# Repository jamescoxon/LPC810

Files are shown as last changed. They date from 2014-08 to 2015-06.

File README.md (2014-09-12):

Adapted from LPC810_CodeBase

* Updated SPI driver
* New driver for RFM69 Radio module
* UART code using interrupt and buffer
* GPS code to read Ublox GPS modules
* Stripped down version of string library
* Included memcpy

Please remember to edit src/main.c and add your own node ID and location string.

LPC810_CodeBase
===============

Open source code base for the ARM Cortex M0+ LPC810 family from NXP.

This code base is intended to work with the LPC810 in a DIP8 package.  While these drivers are based on the original LPC800 example code from NXP, the LPC810 has limited resources (4KB flash and 1KB SRAM), so smaller, lighter-weight drivers had to be written to get the most out of these resources we have.

The current code implements the following peripheral drivers:

- A basic SPI driver
- Some simple GPIO helper functions (although GPIO should normally be accessed directly via the appropriate registers)
- A simple driver for UART0 and printf-redirection that allows 'printf' output to be transmitted to UART0
- A basic multi-rate timer driver that allows us to set delays

The code base also implements a mini printf that takes up much less space than the default printf used in most libc variants.  If necessary, it's easy to change the printf redirection to a location other than UART0 via the printf-redirection.c file.

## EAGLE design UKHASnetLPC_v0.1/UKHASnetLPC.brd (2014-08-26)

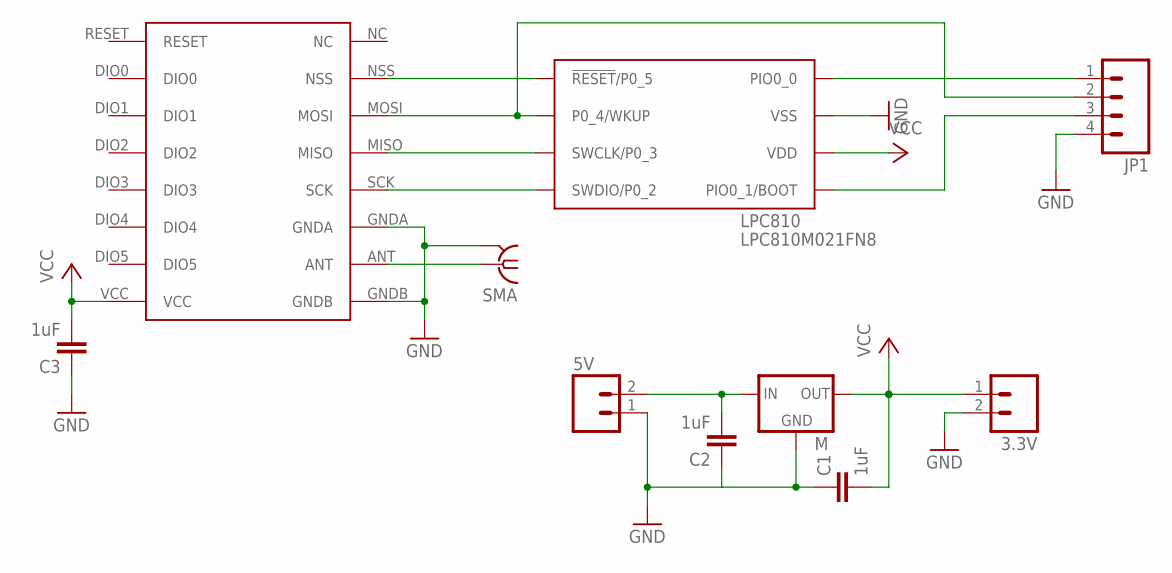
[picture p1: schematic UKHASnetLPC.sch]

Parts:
3.3V, 5V: M02LOCK; 1X02_LOCK
C1, C2, C3: 1uF; CAP-PTH-SMALL
JP1: M04PTH; 1X04
LPC810: LPC810M021FN8; DIP8
M: MCP1700INLINE; TO92-INLINE
RFM69: RFM69HW; RFM
SMA: BUS-SMA

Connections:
GND: 3.3V.2, 5V.1, C1.1, C2.1, C3.1, JP1.4, LPC810.P$7 (VSS), M.1 (GND), RFM69.GNDA, RFM69.GNDB, SMA.2 (GND), SMA.3 (GND), SMA.4 (GND), SMA.5 (GND)
unnamed: LPC810.P$1 (!RESET!/P0_5), RFM69.NSS
unnamed: JP1.2, LPC810.P$2 (P0_4/WKUP), RFM69.MOSI
unnamed: LPC810.P$3 (SWCLK/P0_3), RFM69.MISO
unnamed: LPC810.P$4 (SWDIO/P0_2), RFM69.SCK
unnamed: JP1.3, LPC810.P$5 (PIO0_1/BOOT)
unnamed: JP1.1, LPC810.P$8 (PIO0_0)
unnamed: RFM69.ANT, SMA.1
unnamed: 5V.2, C2.2, M.2 (IN)
VCC: 3.3V.1, C1.2, C3.2, LPC810.P$6 (VDD), M.3 (OUT), RFM69.VCC

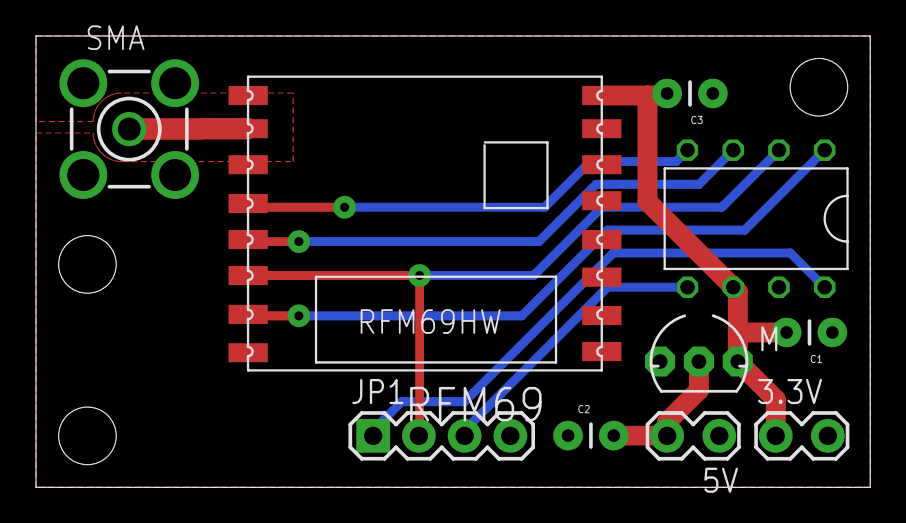
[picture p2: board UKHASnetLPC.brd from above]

Board: 4 copper layers, 46.3 x 25.1 mm, 10 parts (0 on the bottom side), 10 nets.

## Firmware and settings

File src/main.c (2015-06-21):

/**************************************************************************/
/*!
 @file     main.c
 
 @section LICENSE
 
 Software License Agreement (BSD License)
 
 Copyright (c) 2013, K. Townsend (microBuilder.eu)
 All rights reserved.
 
 Modified James Coxon (jacoxon@googlemail.com) 2014-2015
 
 Redistribution and use in source and binary forms, with or without
 modification, are permitted provided that the following conditions are met:
 1. Redistributions of source code must retain the above copyright
 notice, this list of conditions and the following disclaimer.
 2. Redistributions in binary form must reproduce the above copyright
 notice, this list of conditions and the following disclaimer in the
 documentation and/or other materials provided with the distribution.
 3. Neither the name of the copyright holders nor the
 names of its contributors may be used to endorse or promote products
 derived from this software without specific prior written permission.
 
 THIS SOFTWARE IS PROVIDED BY THE COPYRIGHT HOLDERS ''AS IS'' AND ANY
 EXPRESS OR IMPLIED WARRANTIES, INCLUDING, BUT NOT LIMITED TO, THE IMPLIED
 WARRANTIES OF MERCHANTABILITY AND FITNESS FOR A PARTICULAR PURPOSE ARE
 DISCLAIMED. IN NO EVENT SHALL THE COPYRIGHT HOLDER BE LIABLE FOR ANY
 DIRECT, INDIRECT, INCIDENTAL, SPECIAL, EXEMPLARY, OR CONSEQUENTIAL DAMAGES
 (INCLUDING, BUT NOT LIMITED TO, PROCUREMENT OF SUBSTITUTE GOODS OR SERVICES;
 LOSS OF USE, DATA, OR PROFITS; OR BUSINESS INTERRUPTION) HOWEVER CAUSED AND
 ON ANY THEORY OF LIABILITY, WHETHER IN CONTRACT, STRICT LIABILITY, OR TORT
 (INCLUDING NEGLIGENCE OR OTHERWISE) ARISING IN ANY WAY OUT OF THE USE OF THIS
 SOFTWARE, EVEN IF ADVISED OF THE POSSIBILITY OF SUCH DAMAGE.
 */
/**************************************************************************/
//Node settings have been moved seperate file "settings.h"
#include "settings.h"

#include <stdio.h>
#include "LPC8xx.h"
#include "mrt.h"
#include "spi.h"
#include "rfm69.h"

#ifdef defined(GATEWAY) || defined(DEBUG) || defined(GPS)
    #include "uart.h"
#endif

#ifdef GPS
    #include "gps.h"
#endif

#ifdef ADC
    #include "adc.h"
#endif

#ifdef ZOMBIE
    #include "zombie.h"
#endif

#ifdef SERIAL_IN
    #include "uart.h"
    char data_out_temp[MAX_TX_CHARS+1];
#endif

char data_temp[66];

uint8_t data_count = 96; // 'a' - 1 (as the first function will at 1 to make it 'a'
unsigned int rx_packets = 0, random_output = 0, rx_restarts = 0;
int16_t rx_rssi, floor_rssi, rssi_threshold, adc_result = 0;
/**
 * Setup all pins in the switch matrix of the LPC810
 */
void configurePins() {
    /* Enable SWM clock */
    LPC_SYSCON->SYSAHBCLKCTRL |= (1<<7);
    
    /* Pin Assign 8 bit Configuration */
    /* U0_TXD */
    LPC_SWM->PINASSIGN0 = 0xffffff00UL;
    /* SPI0_SCK */
    LPC_SWM->PINASSIGN3 = 0x02ffffffUL;
    /* SPI0_MOSI */
    /* SPI0_MISO */
    /* SPI0_SSEL */
    LPC_SWM->PINASSIGN4 = 0xff050304UL;
    
    /* Pin Assign 1 bit Configuration */
    /* ACMP_I2 */
    LPC_SWM->PINENABLE0 = 0xfffffffdUL;
    
}

#ifdef SERIAL_IN
/**
 * Checks for incoming serial data which will be send by radio. This function
 * also checks the buffers length to avoid a stackoverflow at the radio FIFO.
 */
inline void checkTxBuffer(void) {
	uint8_t i;

	if(UART0_available() > 0) {
		for(i=0; i<serialBuffer_write; i++) {

			if(serialBuffer[i] == '\r' ||  serialBuffer[i] == '\n' || strlen(data_out_temp) >= 32) { // Transmit data from buffer

				#ifdef DEBUG
				if(strlen(data_out_temp) >= MAX_TX_CHARS)
					printf("max. buffer exceeded\r\n");
				#endif

				// Transmit data
				incrementPacketCount();

				uint8_t n;
				data_temp[0] = '\0';

				n = sprintf(data_temp, "%d%c%s[%s]", NUM_REPEATS, data_count, data_out_temp, NODE_ID);
				transmitData(n);

				data_out_temp[0] = '\0'; // Flush buffer

			} else {
				sprintf(data_out_temp, "%s%c", data_out_temp, serialBuffer[i]); // Read from serial buffer
			}

		}
		serialBuffer_write = 0;
	}
}
#endif

/**
 * Packet data transmission
 * @param Packet length
 */
void transmitData(uint8_t i) {

    #ifdef GATEWAY
        printf("rx: %s|0\r\n", data_temp);
    #endif

#ifdef ZOMBIE_MODE
    if (data_count == 97) {
       RFM69_send(data_temp, i, 10);
    }
    else {
        // Transmit the data (need to include the length of the packet and power in dbmW)
        RFM69_send(data_temp, i, POWER_OUTPUT);
    }

    RFM69_setMode(RFM69_MODE_SLEEP);
#else
    
    // Transmit the data (need to include the length of the packet and power in dbmW)
    RFM69_send(data_temp, i, POWER_OUTPUT);
    
    //Ensure we are in RX mode
    RFM69_setMode(RFM69_MODE_RX);
#endif

}

/**
 * This function is called when a packet is received by the radio. It will
 * process the packet.
 */
inline void processData(uint32_t len) {
    uint8_t i, packet_len;
    
    for(i=0; i<len; i++) {
        //finds the end of the packet
        if(data_temp[i] != ']')
            continue;
        
        //then terminates the string, ignore everything afterwards
        data_temp[i+1] = '\0';
        
        //Check validity of string
        // 1) is the first position in array a number
        //printf("%d\r\n", data_temp[0]);
        if((int)data_temp[0] <= 48 || (int)data_temp[0] > 57) {
            //printf("Error1\r\n");
            break;
        }
        
        // 2) is the second position in array a letter
        //      < 'a' or > 'z' then break
        //printf("%d\r\n", data_temp[1]);
        if((int)data_temp[1] < 97 || (int)data_temp[1] > 122){
            //printf("Error2\r\n");
            break;
        }
        
#ifdef GATEWAY
        printf("rx: %s|%d\r\n",data_temp, RFM69_lastRssi());
#endif
        //Reduce the repeat value
        data_temp[0] = data_temp[0] - 1;
        //Now add , and end line and let string functions do the rest
        data_temp[i] = ',';
        data_temp[i+1] = '\0';
        
        if(strstr(data_temp, NODE_ID) != 0)
            break;
        
        strcat(data_temp, NODE_ID); // Add ID
        strcat(data_temp, "]"); // Add ending
        
        packet_len = strlen(data_temp);
        mrtDelay(random_output); // Random delay to try and avoid packet collision
        
        rx_packets++;
        
        transmitData(packet_len);
        break;
    }
}

/**
 * It processing incoming data by the radio or serial connection. This function
 * has to be continously called to keep the node running. This function also
 * adds a delay which is specified as 100ms per unit. Therefore 1000 = 100 sec
 * @param countdown delay added to this function
 */
void awaitData(int countdown) {

    uint8_t rx_len, flags1, old_flags1 = 0x90;

    //Clear buffer
    data_temp[0] = '\0';

    RFM69_setMode(RFM69_MODE_RX);

    rx_restarts = 0;

    while(countdown > 0) {

        flags1 = spiRead(RFM69_REG_27_IRQ_FLAGS1);
#ifdef DEBUG
        if (flags1 != old_flags1) {
            printf("f1: %02x\r\n", flags1);
            old_flags1 = flags1;
        }
#endif
        if (flags1 & RF_IRQFLAGS1_TIMEOUT) {
            // restart the Rx process
            spiWrite(RFM69_REG_3D_PACKET_CONFIG2, spiRead(RFM69_REG_3D_PACKET_CONFIG2) | RF_PACKET2_RXRESTART);
            rx_restarts++;
            // reset the RSSI threshold
            floor_rssi = RFM69_sampleRssi();
#ifdef DEBUG
            // and print threshold
            printf("Restart Rx %d\r\n", RFM69_lastRssiThreshold());
#endif
        }
        // Check rx buffer
        if(RFM69_checkRx() == 1) {
            RFM69_recv(data_temp,  &rx_len);
            data_temp[rx_len - 1] = '\0';
            processData(rx_len);
        }

        #ifdef SERIAL_IN
                // Check tx buffer
                checkTxBuffer();
        #endif

        countdown--;
        mrtDelay(100);
    }
}

/**
 * Increments packet count which is transmitted in the beginning of each
 * packet. This function has to be called every packet which is initially
 * transmitted by this node.
 * Packet count is starting with 'a' and continues up to 'z', thereafter
 * it's continuing with 'b'. 'a' is only transmitted at the very first
 * transmission!
 */
void incrementPacketCount(void) {
    data_count++;
    // 98 = 'b' up to 122 = 'z'
    if(data_count > 122) {
        data_count = 98; //'b'
    }
}



int main(void)
{
#ifdef BrownOut
    LPC_SYSCON->BODCTRL = 0x11;  //Should be set to Level 1 (Assertion 2.3V, De-assertion 2.4V) reset
#endif
    
#ifdef GPS
    // Initialise the UART0 block for printf output
    uart0Init(9600);
#elif defined(GATEWAY) || defined(DEBUG)
    // Initialise the UART0 block for printf output
    uart0Init(115200);
#endif
    
    // Configure the multi-rate timer for 1ms ticks
    mrtInit(__SYSTEM_CLOCK/1000);

    /* Enable AHB clock to the Switch Matrix , UART0 , GPIO , IOCON, MRT , ACMP */
    LPC_SYSCON->SYSAHBCLKCTRL |= (1 << 7) | (1 << 14) /*| (1 << 6)*//* | (1 << 18)*/
    | (1 << 10) | (1 << 19);
    
    // Configure the switch matrix (setup pins for UART0 and SPI)
    configurePins();

    
#ifdef DEBUG
    printf("Node Booted\r\n");
#endif
    
#ifdef ADC
    /* Initialise the comparator ICMP_2 */
    LPC_SYSCON->PDRUNCFG &= ~((1 << 15)); // power up ACMP
#endif
    
    //Seed random number generator, we can use our 'unique' ID
    random_output = NODE_ID[0] + NODE_ID[1] + NODE_ID[2];
    
    RFM69_init();
    
#ifdef ZOMBIE_MODE
    RFM69_setMode(RFM69_MODE_SLEEP);
    init_sleep();
    sleepMicro(60000);
#endif
    
#ifdef GPS
		int navmode = 9;
		setupGPS();
#endif
    
#ifdef DEBUG
		printf("Node initialized, version %s\r\n",GIT_VER);
#endif
    
    while(1) {
        
#ifdef GPS
			mrtDelay(5000);
			navmode = gps_check_nav();
            if (navmode != 6){
                setupGPS();
            }
        
			mrtDelay(500);
			gps_get_position();
			mrtDelay(500);
			gps_check_lock();
			mrtDelay(500);

			//printf("Data: %d,%d,%d,%d,%d,%d\r\n", lat, lon, alt, navmode, lock, sats);
			//printf("Errors: %d,%d\r\n", GPSerror, serialBuffer_write);
#endif
        
        incrementPacketCount();
        
        //Clear buffer
        data_temp[0] = '\0';
        uint8_t n;
        
        //Create the packet
        int int_temp = RFM69_readTemp(); // Read transmitter temperature
        rx_rssi = RFM69_lastRssi();
        // read the rssi threshold before re-sampling noise floor which will change it
        rssi_threshold = RFM69_lastRssiThreshold();
        floor_rssi = RFM69_sampleRssi();
        
#ifdef ADC
        //Read ADC
        adc_result = read_adc2();
#endif

#ifdef BrownOut
        adc_result = acmpVccEstimate();
        // Before transmitting if the input V is too low we could sleep again
        if (adc_result < 3100) {
            sleepRadio();
        }
#endif
        
#ifdef DEBUG
        printf("ADC: %d\r\n", adc_result);

#endif

        if(data_count == 97) {
            n = sprintf(data_temp, "%d%cL%s[%s]", NUM_REPEATS, data_count, LOCATION_STRING, NODE_ID);
        }
        else {
            
#ifdef GPS
            n = sprintf(data_temp, "%d%cL%d,%d,%dT%dR%d[%s]", NUM_REPEATS, data_count, lat, lon, alt, int_temp, rx_rssi, NODE_ID);
#elif defined(DEBUG)
            n = sprintf(data_temp, "%d%cT%dR%d,%dC%dX%d,%dV%d[%s]", NUM_REPEATS, data_count, int_temp, rx_rssi, floor_rssi, rx_packets, rx_restarts, rssi_threshold, adc_result, NODE_ID);
#elif defined(ADC)
            n = sprintf(data_temp, "%d%cT%dR%dV%d[%s]", NUM_REPEATS, data_count, int_temp, rx_rssi, adc_result, NODE_ID);
#elif defined(BrownOut)
            n = sprintf(data_temp, "%d%cT%dV%d[%s]", NUM_REPEATS, data_count, int_temp, adc_result, NODE_ID);
#else
            n = sprintf(data_temp, "%d%cT%dR%d[%s]", NUM_REPEATS, data_count, int_temp, rx_rssi, NODE_ID);
#endif
        }
        
        transmitData(n);

#ifdef BrownOut
        int rx_count = 0;
        
        if(data_count == 97) {
            sleepRadio(); //after first packet will need to sleep longer as probably low light conditions
        }
        else {
            //in good light conditions we can try and rx and then sleep afterwards
            while ((acmpVccEstimate() > 4000) && rx_count < 20) {
                    awaitData((TX_GAP / 20));
                    rx_count++;
                }
        }
        
        sleepRadio(); // so sleep again!
        
        

#elif defined(ZOMBIE_MODE)
        sleepRadio();
#else
        awaitData(TX_GAP);
#endif
    
         }
    
}

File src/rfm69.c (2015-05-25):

// RFM69.cpp
//
// Ported to LPC810 2014 James Coxon
// Ported to Arduino 2014 James Coxon
//
// Copyright (C) 2014 Phil Crump
//
// Based on RF22 Copyright (C) 2011 Mike McCauley ported to mbed by Karl Zweimueller
// Based on RFM69 LowPowerLabs (https://github.com/LowPowerLab/RFM69/)

#include "rfm69.h"
#include "RFM69Config.h"
#include "spi.h"
#include <string.h>
#include <stdio.h>

void* memcpy(void* dest, const void* src, size_t count) {
    char* dst8 = (char*)dest;
    char* src8 = (char*)src;
    
    while (count--) {
        *dst8++ = *src8++;
    }
    return dest;
}

void RFM69_setMode(uint8_t newMode)
{
    spiWrite(RFM69_REG_01_OPMODE, (spiRead(RFM69_REG_01_OPMODE) & 0xE3) | newMode);
    _mode = newMode;
}

uint8_t RFM69_init()
{
    mrtDelay(12);
    
    //Configure SPI
    spiInit(LPC_SPI0,24,0);
    
    mrtDelay(100);
    
    // Set up device
    uint8_t i;
    for (i = 0; CONFIG[i][0] != 255; i++)
        spiWrite(CONFIG[i][0], CONFIG[i][1]);
    
    _rssi_threshold = spiRead(RFM69_REG_29_RSSI_THRESHOLD);
    RFM69_setMode(_mode);
    
    // Clear TX/RX Buffer
    _bufLen = 0;
    
    return 1;
}

void RFM69_spiFifoWrite(const uint8_t* src, int len)
{
    
    spiTransmit(LPC_SPI0, (RFM69_REG_00_FIFO | RFM69_SPI_WRITE_MASK), 9);
    spiReceive(LPC_SPI0);
    
    spiTransmit(LPC_SPI0, len, 9);
    spiReceive(LPC_SPI0);
    
    len--;
    
    uint8_t i = 0;
    while (len >= 0){
        spiTransmit(LPC_SPI0, src[i], len);
        spiReceive(LPC_SPI0);
        
        len--;
        i++;
    }
}

uint8_t  RFM69_mode()
{
    return _mode;
}

void RFM69_clearFifo() {
    // Must only be called in RX Mode
    // Apparently this works... found in HopeRF demo code
    RFM69_setMode(RFM69_MODE_STDBY);
    RFM69_setMode(RFM69_MODE_RX);
}

uint8_t RFM69_checkRx()
{
    // Check IRQ register for payloadready flag (indicates RXed packet waiting in FIFO)
    if(spiRead(RFM69_REG_28_IRQ_FLAGS2) & RF_IRQFLAGS2_PAYLOADREADY) {
        // Get packet length from first byte of FIFO
        _bufLen = spiRead(RFM69_REG_00_FIFO)+1;
        // Read FIFO into our Buffer
        spiBurstRead(RFM69_REG_00_FIFO, _buf, RFM69_FIFO_SIZE);
        // Read RSSI register (should be of the packet? - TEST THIS)
        _lastRssi = -(spiRead(RFM69_REG_24_RSSI_VALUE)/2);
        // Clear the radio FIFO (found in HopeRF demo code)
        RFM69_clearFifo();
        return 1;
    }
    
    return 0;
}

void RFM69_recv(uint8_t* buf, uint8_t* len)
{
    // Copy RX Buffer to byref Buffer
    memcpy(buf, _buf, _bufLen);
    *len = _bufLen;
    // Clear RX Buffer
    _bufLen = 0;
}

void RFM69_send(const uint8_t* data, uint8_t len, uint8_t power)
{
    // power is TX Power in dBmW (valid values are 2dBmW-20dBmW)
    if(power<2 || power >20) {
        // Could be dangerous, so let's check this
        return;
    }
    uint8_t oldMode = _mode;
    // Copy data into TX Buffer
    memcpy(_buf, data, len);
    // Update TX Buffer Size
    _bufLen = len;
    
    RFM69_clearFifo();
    
    // Start Transmitter
    RFM69_setMode(RFM69_MODE_TX);
    // Set up PA
    if(power<=17) {
        // Set PA Level
        uint8_t paLevel = power + 14;
        spiWrite(RFM69_REG_11_PA_LEVEL, RF_PALEVEL_PA0_OFF | RF_PALEVEL_PA1_ON | RF_PALEVEL_PA2_ON | paLevel);
    } else {
        // Disable Over Current Protection
        spiWrite(RFM69_REG_13_OCP, RF_OCP_OFF);
        // Enable High Power Registers
        spiWrite(RFM69_REG_5A_TEST_PA1, 0x5D);
        spiWrite(RFM69_REG_5C_TEST_PA2, 0x7C);
        // Set PA Level
        uint8_t paLevel = power + 11;
        spiWrite(RFM69_REG_11_PA_LEVEL, RF_PALEVEL_PA0_OFF | RF_PALEVEL_PA1_ON | RF_PALEVEL_PA2_ON | paLevel);
    }
    // Wait for PA ramp-up
    while(!(spiRead(RFM69_REG_27_IRQ_FLAGS1) & RF_IRQFLAGS1_TXREADY)) { };
    // Throw Buffer into FIFO, packet transmission will start automatically
    RFM69_spiFifoWrite(_buf, _bufLen);
    // Clear MCU TX Buffer
    _bufLen = 0;
    // Wait for packet to be sent
    while(!(spiRead(RFM69_REG_28_IRQ_FLAGS2) & RF_IRQFLAGS2_PACKETSENT)) {};
    // Return Transceiver to original mode
    RFM69_setMode(RFM69_MODE_RX);
    // If we were in high power, switch off High Power Registers
    if(power>17) {
        // Disable High Power Registers
        spiWrite(RFM69_REG_5A_TEST_PA1, 0x55);
        spiWrite(RFM69_REG_5C_TEST_PA2, 0x70);
        // Enable Over Current Protection
        spiWrite(RFM69_REG_13_OCP, RF_OCP_ON | RF_OCP_TRIM_95);
    }
}

void RFM69_SetLnaMode(uint8_t lnaMode) {
    // RF_TESTLNA_NORMAL (default)
    // RF_TESTLNA_SENSITIVE
    spiWrite(RFM69_REG_58_TEST_LNA, lnaMode);
}

int RFM69_readTemp()
{
    // Store current transceiver mode
    uint8_t oldMode = _mode;
    // Set mode into Standby (required for temperature measurement)
    RFM69_setMode(RFM69_MODE_STDBY);
	mrtDelay(50);
    // Trigger Temperature Measurement
    spiWrite(RFM69_REG_4E_TEMP1, RF_TEMP1_MEAS_START);
    // Check Temperature Measurement has started
    if(!(RF_TEMP1_MEAS_RUNNING & spiRead(RFM69_REG_4E_TEMP1))){
        return 255;
    }
    // Wait for Measurement to complete
    while(RF_TEMP1_MEAS_RUNNING & spiRead(RFM69_REG_4E_TEMP1)) { };
    // Read raw ADC value
    uint8_t rawTemp = spiRead(RFM69_REG_4F_TEMP2);
	
    // Set transceiver back to original mode
    RFM69_setMode(oldMode);
    // Return processed temperature value
    int temperature = 168 - rawTemp;
    return temperature;
}

int16_t RFM69_lastRssi() {
    return _lastRssi;
}

int16_t RFM69_sampleRssi() {
    int count = 0;
    uint8_t rssi;

    // Must only be called in RX mode
    if(_mode!=RFM69_MODE_RX) {
        // Not sure what happens otherwise, so check this
        return 0;
    }
    // Set threshold to minimum signal
    spiWrite(RFM69_REG_29_RSSI_THRESHOLD, 0xff);
    // Trigger RSSI Measurement
    spiWrite(RFM69_REG_23_RSSI_CONFIG, RF_RSSI_START);
    // Wait for Measurement to complete
    while(!(RF_RSSI_DONE & spiRead(RFM69_REG_23_RSSI_CONFIG))) {
        // there is a small chance the measurement may not complete
        // so this avoids waiting forever
        if (count++ > 1000) {
            return 1;
        }
    }
    // Read RSSI value
    rssi = spiRead(RFM69_REG_24_RSSI_VALUE);
    // Incrementally adjust threshold to 3dB above noise floor
    if(rssi - 6 < _rssi_threshold) {
        _rssi_threshold--;
    } else {
        _rssi_threshold++;
    }
    spiWrite(RFM69_REG_29_RSSI_THRESHOLD, _rssi_threshold);
    // Restart reception with new threshold
    spiWrite(RFM69_REG_3D_PACKET_CONFIG2, spiRead(RFM69_REG_3D_PACKET_CONFIG2) | RF_PACKET2_RXRESTART);
    // Return RSSI Value
    return -(rssi/2);
}

int16_t RFM69_lastRssiThreshold() {
    return -(_rssi_threshold/2);
}

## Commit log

2014-06-03 merged Synchronus RFM69 lib with current code
2014-06-03 currently is correctly rx'ing data and printing. Appears to be transmitting but not yet confirmed working
    [main.c, rfm69.c]
2014-06-25 removed printf to save space
2014-07-24 updated to work on LPC810 PCB boards (UKHASnet 0.1).
2014-07-25 added internal temperature from the RFM69 so that node actually has data to transmit. Previously it was float but switched to int to save space. all running on new UKHASnet node
2014-07-25 added define to comment out printing to serial to save space
2014-08-20 added eagle files
    [UKHASnetLPC.brd, UKHASnetLPC.sch]
2014-08-21 updated to print own strings
2014-08-21 changed include to lower case as wouldn't work on linux (though strangely worked on OS X )
2014-08-21 Change include to lower case
2014-08-22 switched it from unit8_t to int to allow larger values
2014-08-23 added DL7AD's changes to try and remove current tx bugs
    [main.c, rfm69.c]
2014-08-23 changed ID to NODE_ID and also allowed changes to output power easily
2014-08-24 adapted processing function, switched to using sprintf instead of strcat
2014-08-24 Redesigned board to avoid interference
    [UKHASnetLPC.brd, UKHASnetLPC.sch]
2014-08-25 reversed changes that broke data processing, rolled back to old version of code - now working again
    [main.c]
2014-08-25 fixed bug that was causing node to transmit for too long (in the FiFo write it was overflowing). now more reliable as well as completely transmitting the first string with out the dodgey hack
    [main.c, rfm69.c]
2014-09-01 fixed bug found by Mark where the serial was being setup with 9600 for both GPS and non-GPS modes rather than 115200
    [main.c]
2014-09-02 FIXED bug where repeated packet was actually only at 10mW rather than the pre-defined POWER_OUTPUT. This would explain on the test flight EMF14 we only downlinked packets and didn't get repeated pack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
    [main.c]
2014-09-02 added random number generator (well sort of) and then added random delays to avoid packet clashes
    [main.c]
2014-09-03 switched \n\r to \r\n to allow python to work better (upload scripts etc)
2014-09-04 Currently reports last rssi in packet but not to console - seems to hang if printf of rssi - unsure why. also have added another define to comment out serial in as not always required.
2014-09-11 Print git version at startup
2014-09-11 updated main.c and added rssi for noise floor
    [main.c]
2014-09-14 added new adc feature
2014-09-14 added adc.c and adc.h
2014-10-18 Increased stack size ( qyx_ suggestion was correct )
    [gcc_startup_lpc8xx.c]
2014-10-30 Fix register bit tests in RFM69_readTemp and RFM69_sampleRssi
    [rfm69.c]
2014-10-30 Adjust RSSI threshold to 4dB above measured noise floor
    [rfm69.c]
2014-10-30 Restart rx if it spends too long in RxReady without reaching PayloadReady. Add diagnostics to monitor this behaviour.
    [gcc_startup_lpc8xx.c, main.c]
2014-11-24 Incrementally adjust threshold to 3dB above noise floor
    [main.c, rfm69.c]
2015-04-09 working adc, though not really connecting now to network - needs investigating...
2015-04-14 reverted freq changes, working well currently on my last remaining LPC810 board!
2015-04-14 updated RFM69Config to latest arduino firmware settings
2015-04-14 increased stack size, now gateway passes its own messages (therefore if the rest of network goes down still know its running) code currently running on AB node
2015-04-19 fixed packet checking code, now parses the first 2 chars to ensure they are valid (number followed by a lower case letter) - working code
    [main.c]
2015-04-29 created settings.h.example, removed averaging adc result as read_adc2 already does this
2015-04-29 added zombie mode, where instead of listening for packets the radio is put to sleep inbetween Tx, will conserve significant power
2015-04-29 code tidying, some functions currently won't fit in flash, needs some pruning
    [main.c]
2015-05-20 added new BrownOut define with code from Jeelabs for the LPC810 to measure its own input voltage (don't think it can be used with the adc code activated). Now that it can set its BOD functions it'll 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
    [main.c]
2015-05-25 fixed brownout power saving, if input V drops below threshold then will sleep a bit longer to allow the cap to charge up fully. Need to fix teh temperature reading, if in zombie it doesn't read the a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
    [main.c]
2015-05-25 fixed temperature sensor issue, wasn't giving enough time for the RFM69's mode to change before reading the sensor. Also added BrownOut define to allow access to new code.
    [main.c, rfm69.c]
2015-05-27 reduced the voltage before transmitting as otherwise node gets stuck in a grey zone of txing, sometimes its good to drain the cap fully and reset everything...
    [main.c]
2015-06-21 simplified code further, tested current consumption, can't seem to get it below about 1.5mA
2015-06-21 added some additional sleeps in an attempt to prolong the life of the node, only works if BrownOut defined, won't effect normal function of a repeater LPC node
    [main.c]
2015-06-21 fixed sleep bug, current code running on AH4
    [main.c]

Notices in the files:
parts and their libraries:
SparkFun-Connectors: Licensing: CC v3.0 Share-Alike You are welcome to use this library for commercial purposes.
